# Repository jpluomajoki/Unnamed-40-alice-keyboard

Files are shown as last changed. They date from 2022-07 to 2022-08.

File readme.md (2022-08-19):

# nurinkurin

nurinkurin

*A short description of the keyboard/project*

* Keyboard Maintainer: [Jere Luomajoki](https://github.com/Jere Luomajoki)
* Hardware Supported: *The PCBs, controllers supported*
* Hardware Availability: *Links to where you can find this hardware*

Make example for this keyboard (after setting up your build environment):

    make nurinkurin:default

Flashing example for this keyboard:

    make nurinkurin:default:flash

See the [build environment setup](https://docs.qmk.fm/#/getting_started_build_tools) and the [make instructions](https://docs.qmk.fm/#/getting_started_make_guide) for more information. Brand new to QMK? Start with our [Complete Newbs Guide](https://docs.qmk.fm/#/newbs).

## Bootloader

Enter the bootloader in 3 ways:

* **Bootmagic reset**: Hold down the key at (0,0) in the matrix (usually the top left key or Escape) and plug in the keyboard
* **Physical reset button**: Briefly press the button on the back of the PCB - some may have pads you must short instead
* **Keycode in layout**: Press the key mapped to `RESET` if it is available

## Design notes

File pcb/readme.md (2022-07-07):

Here is the folder for the pcb created in kicad.

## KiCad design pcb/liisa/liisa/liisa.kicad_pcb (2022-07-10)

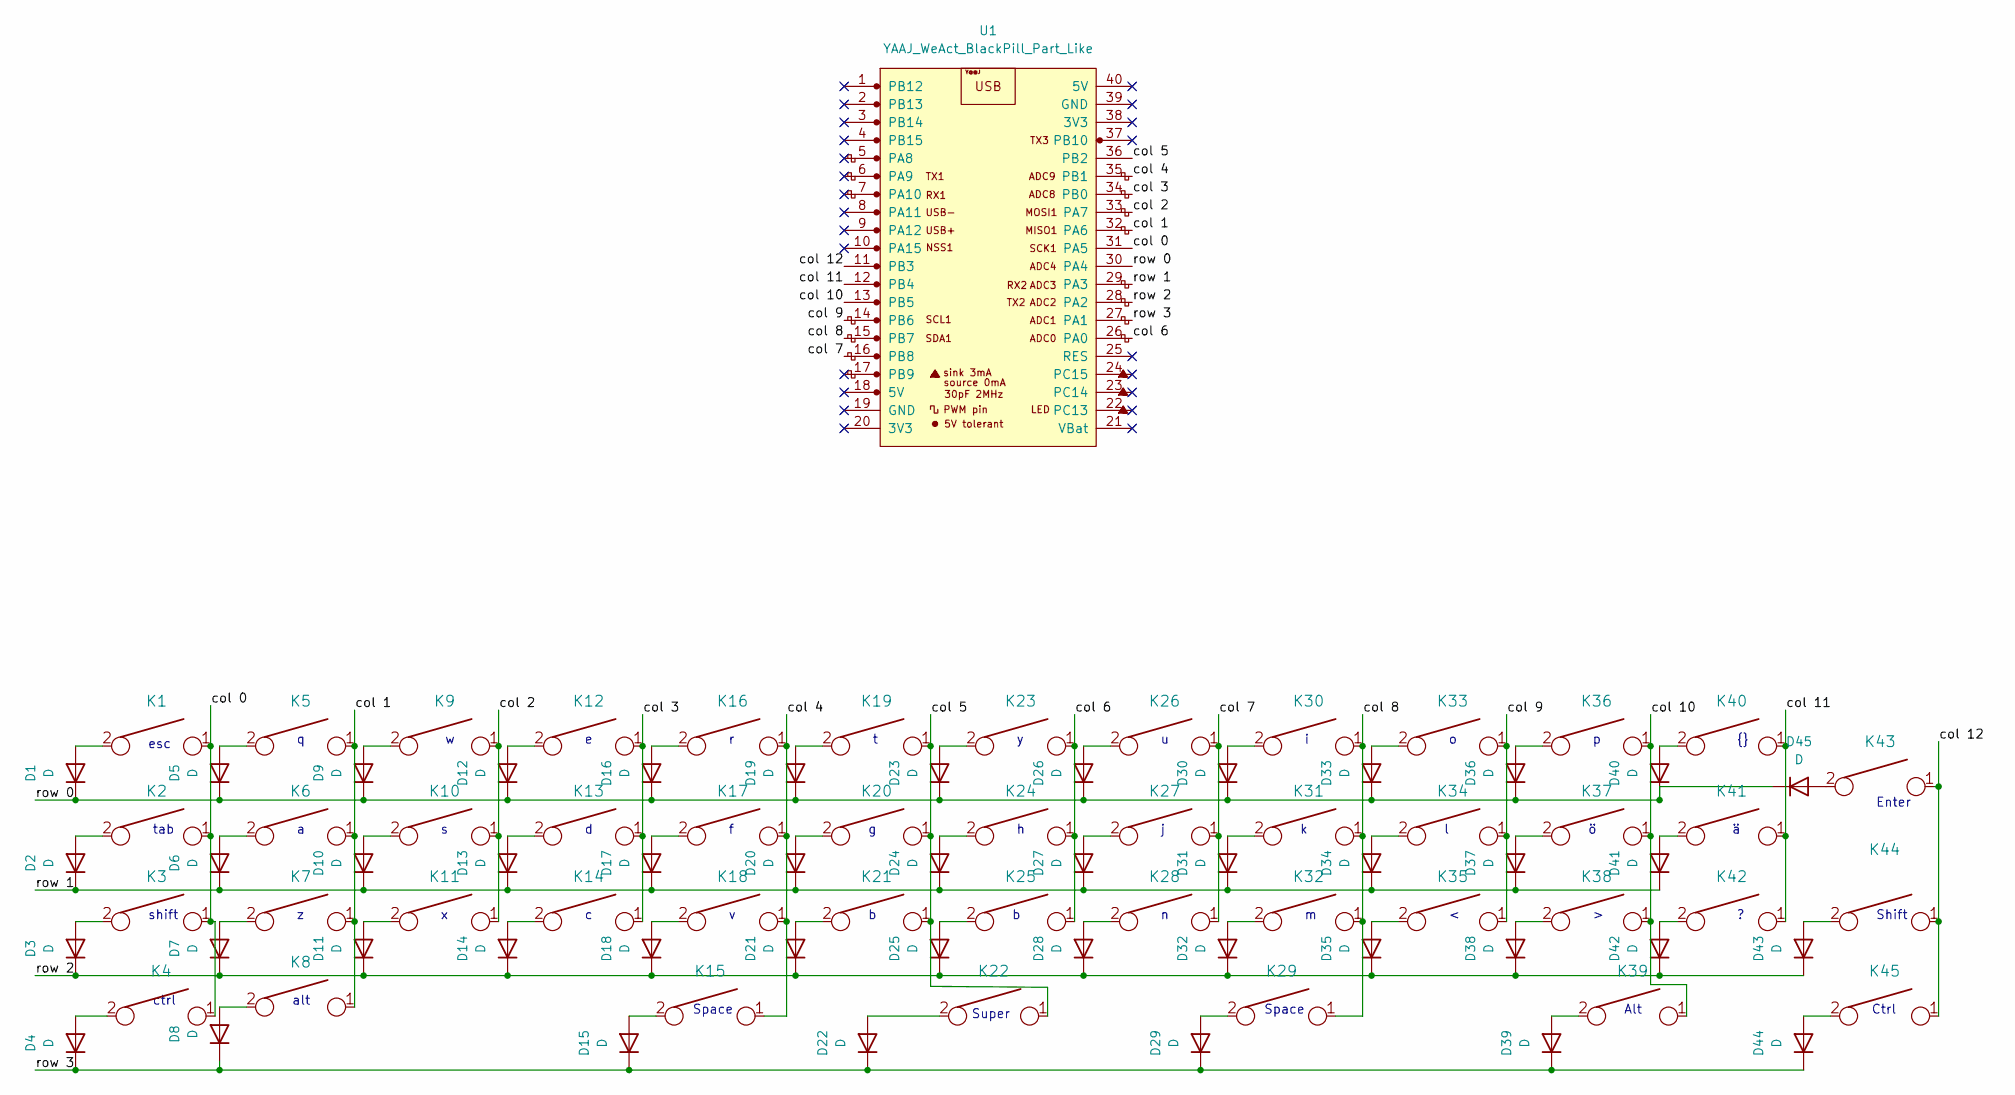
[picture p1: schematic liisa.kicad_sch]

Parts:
D1, D2, D3, D4, D5, D6, D7, D8, D9, D10, D11, D12, D13, D14, D15, D16, D17, D18, D19, D20, D21, D22, D23, D24, D25, D26, D27, D28, D29, D30, D31, D32, D33, D34, D35, D36, D37, D38, D39, D40, D41, D42, D43, D44, D45: D; D_SOD-123F
K1, K5, K6, K7, K9, K10, K11, K12, K13, K14, K16, K17, K18, K19, K20, K21, K22, K23, K24, K25, K26, K27, K28, K30, K31, K32, K33, K34, K35, K36, K37, K38, K40, K41, K42: KEYSW; Mx_Alps_100
K2, K4, K8, K39, K45: KEYSW; Mx_Alps_125
K3, K44: KEYSW; Mx_Alps_150
K15: KEYSW; Mx_Alps_225
K29: KEYSW; Mx_Alps_275
K43: KEYSW; Mx_Alps_200
U1: YAAJ_WeAct_BlackPill_Part_Like; YAAJ_WeAct_BlackPill_2

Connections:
/col 0: K1.1, K2.1, K3.1, K4.1, U1.31 (PA5)
/col 1: K5.1, K6.1, K7.1, K8.1, U1.32 (PA6)
/col 2: K9.1, K10.1, K11.1, U1.33 (PA7)
/col 3: K12.1, K13.1, K14.1, U1.34 (PB0)
/col 4: K15.1, K16.1, K17.1, K18.1, U1.35 (PB1)
/col 5: K19.1, K20.1, K21.1, K22.1, U1.36 (PB2)
/col 6: K23.1, K24.1, K25.1, U1.26 (PA0)
/col 7: K26.1, K27.1, K28.1, U1.16 (PB8)
/col 8: K29.1, K30.1, K31.1, K32.1, U1.15 (PB7)
/col 9: K33.1, K34.1, K35.1, U1.14 (PB6)
/col 10: K36.1, K37.1, K38.1, K39.1, U1.13 (PB5)
/col 11: K40.1, K41.1, K42.1, U1.12 (PB4)
/col 12: K43.1, K44.1, K45.1, U1.11 (PB3)
/row 0: D1.1 (K), D5.1 (K), D9.1 (K), D12.1 (K), D16.1 (K), D19.1 (K), D23.1 (K), D26.1 (K), D30.1 (K), D33.1 (K), D36.1 (K), D40.1 (K), D45.1 (K), U1.30 (PA4)
/row 1: D2.1 (K), D6.1 (K), D10.1 (K), D13.1 (K), D17.1 (K), D20.1 (K), D24.1 (K), D27.1 (K), D31.1 (K), D34.1 (K), D37.1 (K), D41.1 (K), U1.29 (PA3)
/row 2: D3.1 (K), D7.1 (K), D11.1 (K), D14.1 (K), D18.1 (K), D21.1 (K), D25.1 (K), D28.1 (K), D32.1 (K), D35.1 (K), D38.1 (K), D42.1 (K), D43.1 (K), U1.28 (PA2)
/row 3: D4.1 (K), D8.1 (K), D15.1 (K), D22.1 (K), D29.1 (K), D39.1 (K), D44.1 (K), U1.27 (PA1)
unnamed: D1.2 (A), K1.2
unnamed: D2.2 (A), K2.2
unnamed: D3.2 (A), K3.2
unnamed: D4.2 (A), K4.2
unnamed: D5.2 (A), K5.2
unnamed: D6.2 (A), K6.2
unnamed: D7.2 (A), K7.2
unnamed: D8.2 (A), K8.2
unnamed: D9.2 (A), K9.2
unnamed: D10.2 (A), K10.2
unnamed: D11.2 (A), K11.2
unnamed: D12.2 (A), K12.2
unnamed: D13.2 (A), K13.2
unnamed: D14.2 (A), K14.2
unnamed: D15.2 (A), K15.2
unnamed: D16.2 (A), K16.2
unnamed: D17.2 (A), K17.2
unnamed: D18.2 (A), K18.2
unnamed: D19.2 (A), K19.2
unnamed: D20.2 (A), K20.2
unnamed: D21.2 (A), K21.2
unnamed: D22.2 (A), K22.2
unnamed: D23.2 (A), K23.2
unnamed: D24.2 (A), K24.2
unnamed: D25.2 (A), K25.2
unnamed: D26.2 (A), K26.2
unnamed: D27.2 (A), K27.2
unnamed: D28.2 (A), K28.2
unnamed: D29.2 (A), K29.2
unnamed: D30.2 (A), K30.2
unnamed: D31.2 (A), K31.2
unnamed: D32.2 (A), K32.2
unnamed: D33.2 (A), K33.2
unnamed: D34.2 (A), K34.2
unnamed: D35.2 (A), K35.2
unnamed: D36.2 (A), K36.2
unnamed: D37.2 (A), K37.2
unnamed: D38.2 (A), K38.2
unnamed: D39.2 (A), K39.2
unnamed: D40.2 (A), K40.2
unnamed: D41.2 (A), K41.2
unnamed: D42.2 (A), K42.2
unnamed: D43.2 (A), K44.2
unnamed: D44.2 (A), K45.2
unnamed: D45.2 (A), K43.2

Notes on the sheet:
Space
esc
alt
Ctrl
Enter
shift
tab
Alt
Shift
ctrl
Super

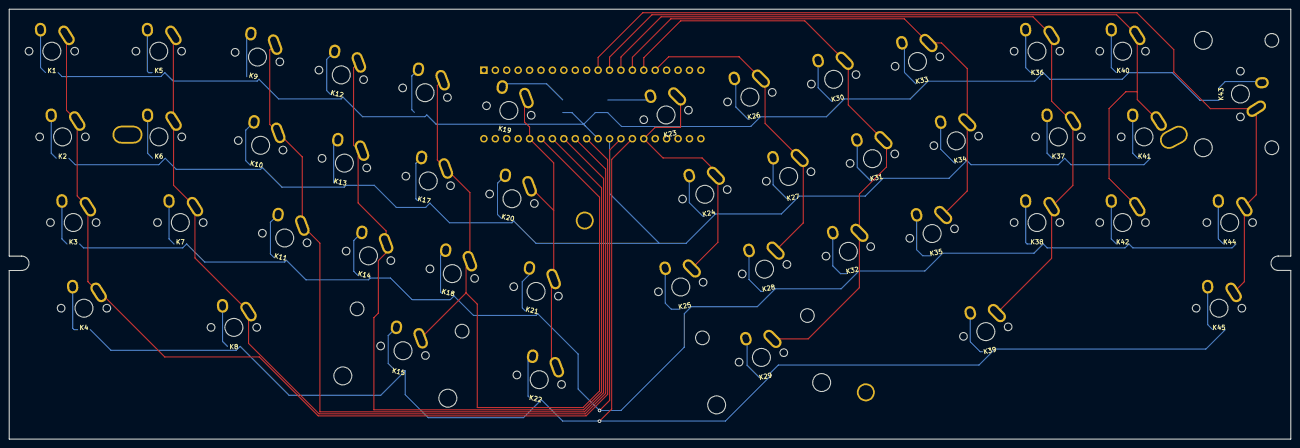
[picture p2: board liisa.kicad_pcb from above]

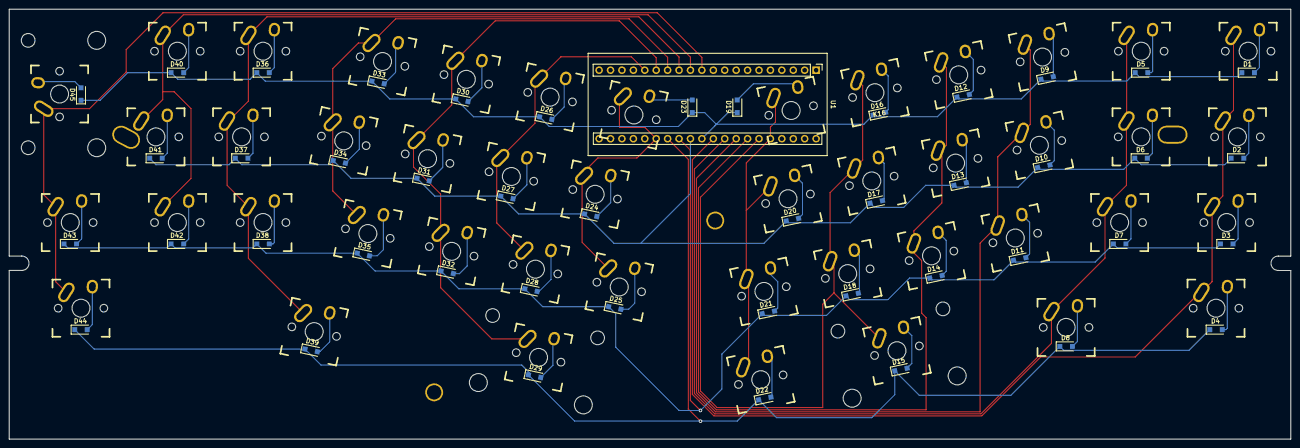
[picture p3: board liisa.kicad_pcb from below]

Board: 2 copper layers, 285.0 x 95.6 mm, 95 parts (91 on the bottom side), 62 nets.

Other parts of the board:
HOLE_M3, HOLE_M3#2, HOLE_M3#3, HOLE_M3#4: VAL**; HOLE_M3

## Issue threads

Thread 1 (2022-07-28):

Flip all switches

jpluomajoki, 2022-07-28:
Switches are on the wrong side of the PCB

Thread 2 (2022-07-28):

Change switch footprints

jpluomajoki, 2022-07-28:
Default kicad footprints for mx switches look better, and include ISO enter, use them instead.

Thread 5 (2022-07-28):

Make a version where the MCU does not overlap with switches

jpluomajoki, 2022-07-28:
This version of the pcb will not fit within 60% case without removing switches, make it bigger and sandwich case

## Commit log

2022-07-07 Create readme.md for pcb.
2022-07-07 Add PCB made in kicad
    [liisa.kicad_pcb, liisa.kicad_sch]
2022-07-10 Update keyboard, add gerbers.
    [liisa-B_Cu.gbl, liisa-B_Mask.gbs, liisa-B_Paste.gbp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]
